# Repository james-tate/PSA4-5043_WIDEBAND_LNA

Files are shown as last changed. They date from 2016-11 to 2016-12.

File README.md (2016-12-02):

#PSA4-5043 LNA with onboard Bias tee designed for use with RTL SDR dongles, hackrf, or other SDR. LNA has two power options, USB mini or power from inline. There is also an option for an on-board wideband bias tee and bandpass filter.

"The current board design needs a series resistor between J1 and LED1 in order for the LED to operate. I will redesign the board soon to accommodate the changes. If you have the current board design, the trace can be cut betweeen the components and a 470ohm resistor can be put in its place."

[PSA4-5043 ](http://www.minicircuits.com/pdfs/PSA4-5043+.pdf) -- .05 to 4GHz  

[TCBT-14+ Bias Tee](http://www.minicircuits.com/pdfs/TCBT-14+.pdf) -- 10MHz to 10GHz  

[Optional bandpass filter](http://www.minicircuits.com/products/filters_sm_bandpass.shtml). 

 You can order the 3 copies of the board from Oshpark for $4.75 

Feel free to contact me  if any questions or if you suggest changes.

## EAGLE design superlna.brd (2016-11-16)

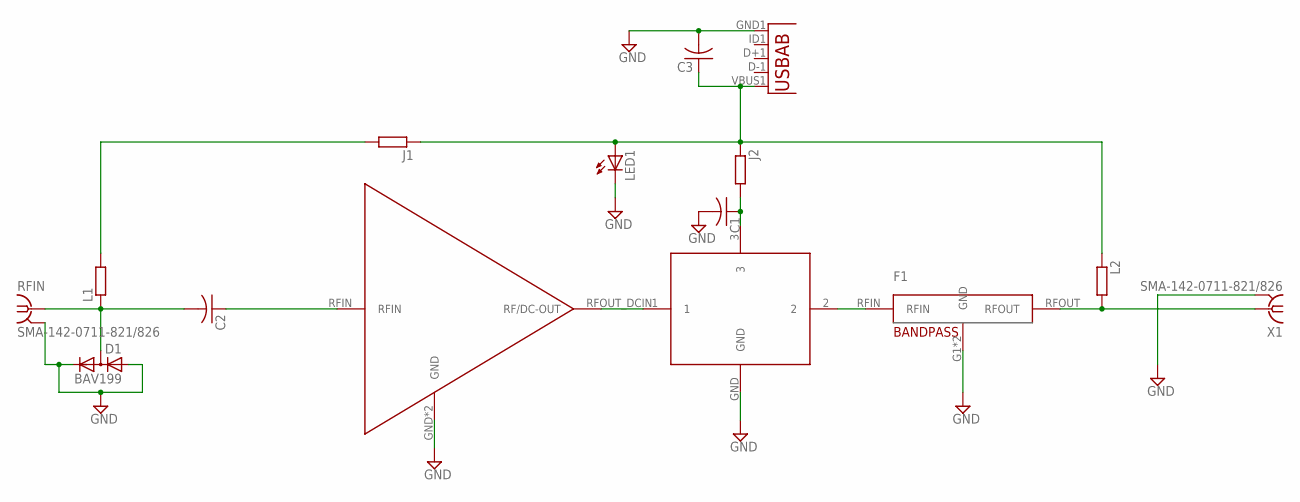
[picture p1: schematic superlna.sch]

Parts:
C1, C2, C3: C-USC0402; C0402
D1: BAV199; SOT23
F1: BANDPASS; FV1206
J1, J2: R-EU_R0805; R0805
L1, L2: R-EU_R0805; R0805
LED1: LED_ESML0603; LED_SML0603
LNA: AMP; SOC-343
POWER: USB""; USB-MICRO-SMD
RFIN: SMA-142-0711-821/826; J502-ND-142-0711-821/826
U1: BIASTEE; GU1414
X1: SMA-142-0711-821/826; J502-ND-142-0711-821/826

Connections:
BIASPOWER: C1.1, J2.2, U1.3
GND: C1.2, C3.2, D1.1 (A), D1.2 (C), F1.G1 (GND), F1.G2 (GND), LED1.C, LNA.GND, LNA.GND1 (GND), POWER.GND1 (GND), RFIN.G@1 (2), RFIN.G@2 (2), RFIN.G@3 (2), RFIN.G@4 (2), U1.GND, X1.G@1 (2), X1.G@2 (2), X1.G@3 (2), X1.G@4 (2)
unnamed: C2.1, LNA.RFIN
unnamed: LNA.RFOUT_DCIN (RF/DC-OUT), U1.1
unnamed: J1.2, L1.2
PWRIN: C3.1, J1.1, J2.1, L2.1, LED1.A, POWER.VBUS1 (VBUS)
RFIN: C2.2, D1.3 (AC), L1.1, RFIN.1
RFOUT: F1.RFOUT, L2.2, X1.1
RFOUT1: F1.RFIN, U1.2

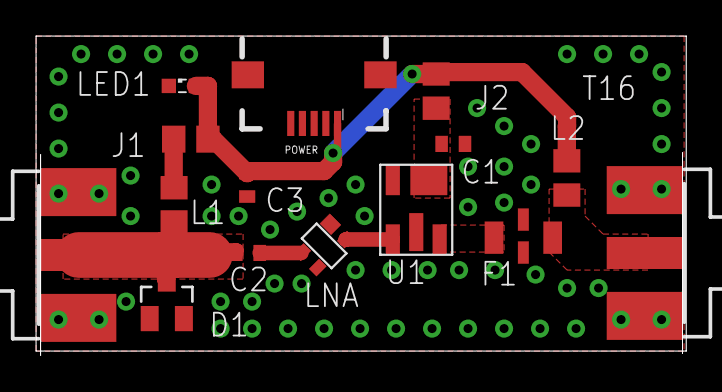
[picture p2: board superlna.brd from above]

Board: 2 copper layers, 36.1 x 17.5 mm, 15 parts (0 on the bottom side), 9 nets.

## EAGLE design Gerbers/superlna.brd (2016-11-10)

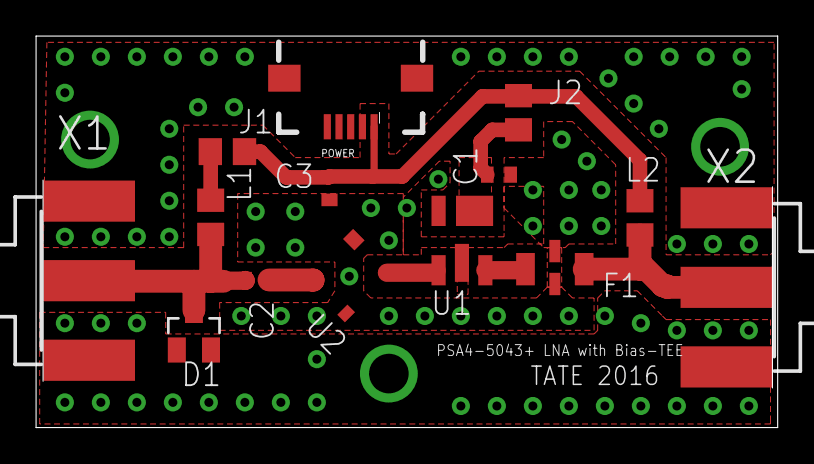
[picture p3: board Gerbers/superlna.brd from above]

Board: 2 copper layers, 41.2 x 21.8 mm, 14 parts (0 on the bottom side), 9 nets.

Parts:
C1, C2, C3: C0402
D1: BAV199; SOT23
F1: BANDPASS; FV1206
J1, J2: R0805
L1, L2: R0805
POWER: USB-MICRO-SMD
U1: BIASTEE; GU1414
U2: AMP; SOC-343
X1, X2: SMA-142-0701-801/806; J502-ND-142-0701-801/806

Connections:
BIASPOWER: C1.1, J2.2, U1.3
GND: C1.2, C3.2, D1.1, D1.2, F1.G1, F1.G2, POWER.GND1, U1.GND, U2.GND, U2.GND1, X1.G@1, X1.G@2, X1.G@3, X1.G@4, X2.G@1, X2.G@2, X2.G@3, X2.G@4
unnamed: C2.1, U2.RFIN
unnamed: C3.1, J1.1, J2.1, L2.1, POWER.VBUS1
unnamed: U1.1, U2.RFOUT_DCIN
unnamed: F1.RFIN, U1.2
unnamed: J1.2, L1.2
RFIN: C2.2, D1.3, L1.1, X1.1
RFOUT: F1.RFOUT, L2.2, X2.1

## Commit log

2016-11-10 changed some traces for better 50ohm
    [superlna.brd]
2016-11-14 changes to V1
    [superlna.brd, superlna.sch]
